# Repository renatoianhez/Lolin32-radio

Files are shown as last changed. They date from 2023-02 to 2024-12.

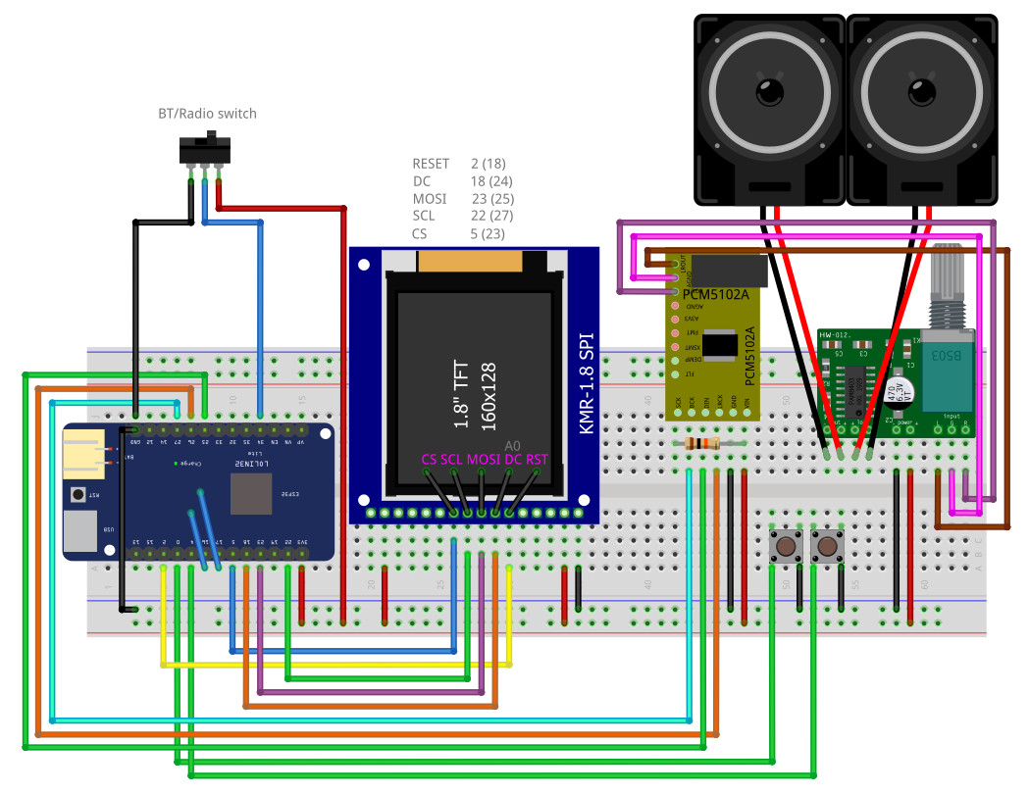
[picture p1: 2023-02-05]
RadioeBT/Fritzing.jpg

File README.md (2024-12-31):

# Lolin32-radio
This is another project like others out there: a web radio with ESP32.

New update: I put a bluetooth mode through an SPDT switch. Look in the RadioeBT folder.

The best update so far: it's possible to update your list of radio stations via a text file in GIST! See it on RadioWeb example. This is important because radio stations often change their URLs. In my case, as I make the radio sets as gifts to my friends, I won't need to get the sets back to update them. Although it is a good reason to visit them!

This radio uses Lolin32 Lite (with a PSRAM update, which makes it equivalent to an ESP32 WROVER), a 1.8'' SPI screen and I2S with PCM5102 + PAM8403 amp:



The libraries used are:

ESP32-audioI2S: https://github.com/schreibfaul1/ESP32-audioI2S

TFT_eSPI: https://github.com/Bodmer/TFT_eSPI

Bluetooth: https://github.com/pschatzmann/ESP32-A2DP

Add the PSRAM:



https://blog.pagefault-limited.co.uk/lolin32-lite-esp32-8mb-psram-upgrade-mod

With PSRAM, the Lolin32 Lite works like a WROVER Kit. The Arduino IDE configuration looks like this:


After audio library updates, it is possible to play HLS streams!
I'm assembling it in a wooden box.

Imagem do WhatsApp de 2023-02-05 à(s) 17 16 38



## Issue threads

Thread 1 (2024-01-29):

No Issue, just a question:  How to transmit a radio stream to a bluetooth speaker

chess-levin, 2024-01-29:
Hello @renatoianhez ,
thank you for sharing your excellent work here on github!

I've recently built my own web radio based on this projects

* https://github.com/schreibfaul1/ESP32-audioI2S/tree/master/examples/Better_WiFi_throughput
* https://github.com/schreibfaul1/ESP32-MiniWebRadio

I had troubles to get a smooth, uninterrupted audio experience unless I found the previously mentioned code/project. The TCP-stream broke down every now and then. So I had to reconfigure the TCP-Settings used by the Arduino framework.

Now the receiving part is fine, but I'm missing a way to transmit the sound to one of my Bluetooth speakers. As a workaround I bought a TX/RX-Transceiver (amazon) that converts the analogue lineout-signal and sends it via Bluetooth to a speaker. Obviously it is nuts, to first send the audio stream through a DAC + a class D amp and afterwards convert it back to a digital signal. So your project seems to be a solution to this problem.

During my research I found several sources that were saying, ESP32 is not good for transmitting audio via BT. I was wondering if receiving a audio-stream via TCP and sending audio via BT in parallel is a problem that causes interrupted sound and therefore a bad listening experience.

Maybe you could share some deeper information on your BT solution and about the sound quality.

As far as I understand you use BT as an input source and not as an output sink - correct?

Thank you very much in advance!

renatoianhez, 2024-01-29:
Yes! The Bluetooth function on my radio (when selected on a rear button) is only the reception of the signal generated by another device, such as a cell phone playing music via Spotify. In this case, the radio function is switched off.
Perhaps, in your case, a small dedicated Bluetooth transmission board like [this one](https://pt.aliexpress.com/item/1005005777451417.html) will be the solution to take the audio signal and transmit it.
I believe that transmitting data simultaneously with receiving stream data is also possible using different cores in the ESP32 that are dual core (it would not be possible in the ESP32 C3, for example). However, I don't really understand how to dedicate a task to a specific core. In the [Wolle's audio library](https://github.com/schreibfaul1/ESP32-audioI2S) there are some clues on how to do this.

chess-levin, 2024-01-30:
Tank you for answering my question.
I already ordered this KCX_BT_EMITTER, but as I wrote overall this results in an odd signal chain.
So I'm going to ask pschatzman the author of [audio-tools](https://github.com/pschatzmann/arduino-audio-tools/tree/main), if he could give me tome tips, to get me started on this topic.

chess-levin, 2024-01-30:
So **Wifi & BT is not working together** on an ESP32: https://github.com/pschatzmann/ESP32-A2DP/wiki/WIFI-and-A2DP-Coexistence

Closed 2024-01-30.

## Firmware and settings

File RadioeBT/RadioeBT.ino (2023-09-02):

#include <Arduino.h>
#include <TFT_eSPI.h> // Screen lib
#include <SPI.h> // SPI
#include <WiFi.h> // WiFi lib
#include <WiFiMulti.h> // Multi address WiFi
#include "Audio.h" // Audio lib
#include "examples/320 x 240/Free_Font_Demo/Free_Fonts.h" // Fonts
#include "BluetoothA2DPSink.h" // Bluetooth lib

#define canalPraCima  0   // Switch stations
#define canalPraBaixo 4
#define I2S_DOUT      25  // Audio I2S pins
#define I2S_BCLK      27
#define I2S_LRCK      26
#define modoAparelho  34  // Switch radio-bluetooth

bool mudouEstacao;
int radioTocando;
char* tituloBT;
char* artistaBT;
char* albumBT;

TFT_eSPI tela = TFT_eSPI(); // Screen pins are in library
Audio audio;
BluetoothA2DPSink a2dp_sink;
WiFiMulti outrosWiFi;
bool connected = true;

//Radios and URL's
const char* nomeRadio[30] = {
  "Antena 1",
  "Kiss",
  "Eldorado FM", 
  "Cultura",
  "Itatiaia", 
  "Dominicana",  
  "BFF.fm", 
  "Saudade", 
  "Radio USP", 
  "CBN BH",
  "Radio UFMG",
  "Tribuna",
  "Smooth Jazz",
  "Louge FM",
  "JB FM",
  "Chante France",
  "Guerrilla",
  "Oldie Antenne",
  "Alvorada",
  "Sarau",
  "RadioNOS",
  "Inconfidencia",
  "Axe Bahia",
  "Seresta aoLuar",
  "XFM",
  "Super 70s",
  "Classic Hits",
  "WROD",
  "Univers. UFES",
  "Tonic Ska"
};
const char* tipoRadio[30] = {
  "FM - Hits Internacional",
  "FM - Rock",
  "FM - Noticia/Musica",
  "FM - MPB",
  "AM - Noticia/Musica",
  "Web - Salsa",
  "Web - Indie/Wolrd",
  "FM - Flash Back",
  "FM - MPB",
  "FM - Noticias",
  "FM - MPB/Varios",
  "FM - Hits/Flash Back",
  "Web - Jazz",
  "Web - Acustico/Lounge",
  "FM - Hits/Flash Back",
  "Web - Chanson Francaise",
  "Web - Alternative/Rock",
  "Web - Flash Back/Rock",
  "FM - Hits/Flash Back",
  "FM - MPB/Seresta",
  "Web - Dub/Reggae",
  "FM - MPB/Noticias",
  "Web - Axe",
  "Web - Seresta",
  "FM - Rock",
  "Web - Flash Back/Rock",
  "Web - Flash Back/Rock",
  "FM - Rock",
  "FM - MPB/Samba",
  "Web - Ska/Reggae"
};

const char* cidadeRadio[30] = {
  "Sao Paulo SP",
  "Sao Paulo SP",
  "Sao Paulo SP",
  "Sao Paulo SP",
  "Belo Horizonte MG",
  "Santo Domingo - R. Dom",
  "San Francisco CA - USA",
  "Santos SP",
  "Sao Paulo SP",
  "Belo Horizonte MG",
  "Belo Horizonte MG",
  "Vitoria ES",
  "New York - USA",
  "Kiev - Ucrania",
  "Rio de Janeiro RJ",
  "Paris - Franca",
  "Sarasota FL - USA",
  "Bayern - Alemanha",
  "Belo Horizonte MG",
  "Conservatoria RJ",
  "Fortaleza CE",
  "Belo Horizonte MG",
  "Salvador BA",
  "Taubate SP",
  "Londres - UK",
  "Waynesboro VA - EUA",
  "Waynesboro VA - EUA",
  "Daytona Beach FL - EUA",
  "Vitoria ES",
  "Londres - UK"
};
String urlRadio[] = {    // GL = glitches, OK = no glitches
  "https://antenaone.crossradio.com.br/stream/1;", // Antena 1 OK no tags
  "http://cloud2.cdnseguro.com:23538/;", // Kiss FM OK
  "https://eldoradolive02.akamaized.net/hls/live/2043453/eldorado/master.m3u8", // Eldorado OK no tags
  "https://radiocultura2.jmvstream.com/stream", // Cultura OK no tags
  "http://8903.brasilstream.com.br:8903/stream?1616578451161", // Itatiaia OK
  "http://radio.domiplay.net:2002/;", // Dominicana OK
  "https://ais-sa2.cdnstream1.com/2053_128.mp3", // BFF.FM GL
  "https://24073.live.streamtheworld.com/SAUDADE_FMAAC.aac", // Saudade OK
  "http://flow.emm.usp.br:8007/radiousp-128.mp3", // USP OK no tags
  "https://26513.live.streamtheworld.com/CBN_BHAAC.aac", // CBN OK
  "http://150.164.63.210:8000/aovivo.mp3", // UFMG OK no tags
  "http://cast.midiaip.com.br:6060/stream?1506557548760", // Tribuna GL+
  "https://hestia2.cdnstream.com/1078_128?cb=696226.mp3",  // Smooth Jazz GL
  "http://cast.loungefm.com.ua/acoustic128?1410329161003.mp3", // Louge FM GL
  "https://24083.live.streamtheworld.com/JBFMAAC.aac", // JB GL+
  "https://chantefranceemotion.ice.infomaniak.ch/chantefranceemotion-96.aac", // Chante France GL
  "http://s2.stationplaylist.com:9460/guerrilla", // Guerrilla OK
  "https://s7-webradio.oldie-antenne.de/oldie-antenne", // Antenne Oldies GL+++
  "http://20323.live.streamtheworld.com/RADIO_ALVORADAAAC_SC", // Alvorada OK
  "https://s17.maxcast.com.br:8783/live", // Sarau OK
  "https://nos.radio.br/stream/8/;", // RadioNOS OK
  "https://8446.brasilstream.com.br/stream", // Inconfidencia FM OK
  "http://euroticast5.euroti.com.br:8070/;", // Axe BA OK
  "http://50.3.30.111:8042/stream", // Seresta ao Luar OK
  "http://media-ice.musicradio.com/RadioXLondon", // XFM GL+
  "http://relay.181.fm:8066/", // 181 Super 70 OK
  "http://relay.181.fm:8132/", // 181 Classic OK
  "http://ice7.securenetsystems.net/WROD", // WROD GL+
  "http://8642.brasilstream.com.br/stream?identifica=9725815160273912000&rand=9201410188400340000", //UFES OK
  "https://eu10.fastcast4u.com/tonicska" // Tonic Ska GL++
};

void sobeCanal() {
  // Se apertar o botao pra subir uma estacao:
  radioTocando = radioTocando + 1;          // increments index
  tela.fillScreen(TFT_BLACK);
  tela.setTextColor(TFT_RED, TFT_WHITE);
  tela.setCursor(0, 0, 4);
  tela.println("Sintonizando!");
  delay(1000); // delay for button
  if (radioTocando > 29) {     // Tests if is the last station of list
    radioTocando = 0;         // if yes, go to the first
  }
}

void desceCanal() {
  radioTocando = radioTocando - 1;        // decrements the index
  tela.fillScreen(TFT_BLACK);
  tela.setCursor(0, 0, 4);
  tela.setTextColor(TFT_RED, TFT_WHITE);
  tela.println("Sintonizando!");
  delay(1000); // uma pausa pra largar o botao
  if (radioTocando < 0) { 
    radioTocando = 29; 
  }
}

void mudouEstacaoMesmo() {
  tela.setFreeFont(FF5);
  tela.fillScreen(TFT_BLACK);
  tela.fillRect(0, 0, 160, 28, TFT_WHITE);
  int centro = 77 - (11 * ((strlen(nomeRadio[radioTocando])) / 2));
  tela.setCursor(centro, 18);
  tela.setTextColor(TFT_BLUE); //blue text
  tela.println(nomeRadio[radioTocando]); // centralizes radio name
  tela.setTextFont(2);
  tela.setCursor(0, 30);
  tela.setTextColor(TFT_ORANGE);
  tela.println(cidadeRadio[radioTocando]);
  tela.setCursor(0, 45, 2);
  tela.setTextColor(TFT_YELLOW);
  tela.println(tipoRadio[radioTocando]);
  audio.connecttohost(urlRadio[radioTocando].c_str());
  delay(500);
}
void audio_info(const char *info) {
  Serial.print("info        ");
  Serial.println(info);
}

void audio_showstreamtitle(const char *titulo) { // To show tags
  tela.setCursor(0, 60, 2);
  tela.setTextColor(TFT_CYAN, TFT_BLACK);
  tela.println("Tocando agora:");
  tela.setCursor(0, 75, 2);
  tela.println("                                                                                    "); //Clean tags
  tela.setCursor(0, 75, 2);
  tela.println(titulo);
}

void avrc_metadata_callback(uint8_t id, const uint8_t *text) {
  Serial.printf("==> AVRC metadata rsp: attribute id 0x%x, %s\n", id, text);
  tela.setFreeFont(FF5);
  tela.fillScreen(TFT_BLACK);
  tela.fillRect(0, 0, 160, 28, TFT_WHITE);
  tela.setCursor(28, 18);
  tela.setTextColor(TFT_BLUE); 
  tela.println("BLUETOOTH");
  tela.setTextFont(2);
  tela.setCursor(0, 30);
  switch (id) {
    case ESP_AVRC_MD_ATTR_TITLE:
      tituloBT = (char*) text;
      break;
    case ESP_AVRC_MD_ATTR_ARTIST:
      artistaBT = (char*) text;
      break;
    case ESP_AVRC_MD_ATTR_ALBUM:
      albumBT = (char*) text;
      break;
  }
  tela.setTextColor(TFT_ORANGE);
  tela.println(a2dp_sink.get_peer_name());  // Shows the name of source
  tela.setTextColor(TFT_PINK);
  tela.println(tituloBT);
  tela.setTextColor(TFT_YELLOW);
  tela.println(artistaBT);
  tela.setTextColor(TFT_LIGHTGREY);
  tela.println(albumBT);
}

void setup() {
  pinMode(canalPraCima, INPUT_PULLUP); // Button mode
  pinMode(canalPraBaixo, INPUT_PULLUP);
  pinMode(modoAparelho, INPUT);
  Serial.begin( 115200 );
  tela.init(); // Display init
  tela.setRotation(1); // Screen mode portrait
  tela.invertDisplay(1); // Color adjust for the TFT
  outrosWiFi.addAP("xxx", "xxx"); // WiFi data (user, passw)
  //outrosWiFi.addAP("xxx", "xxx"); // Others WiFi
  //outrosWiFi.addAP("xxx","xxx");

  if (digitalRead(modoAparelho)) {  //If radio mode
    radioTocando = random(0, 30); // Sort the first station
    mudouEstacao = true;
    WiFi.disconnect(); // Wifi connection
    WiFi.mode(WIFI_STA);
    while (outrosWiFi.run() != WL_CONNECTED) delay(1500);

    audio.setPinout(I2S_BCLK, I2S_LRCK, I2S_DOUT); // Radio config
    audio.setVolume(16); // volume zero to 21
    // audio.setConnectionTimeout(2000, 7200); // Grant connection
    audio.setTone(4, 0, 4); // Equalizator bass - mid - terble (-40 to 6)
    audio.setBufsize(0, 4000000);
    // audio.forceMono(true); // Mono
    // audio.setBalance(0); // Balance (-16 to 16)
  }
  else {
    i2s_pin_config_t my_pin_config = {  //If Bluetooth mode
      .bck_io_num = 27,
      .ws_io_num = 26,
      .data_out_num = 25,
      .data_in_num = I2S_PIN_NO_CHANGE
    };
    a2dp_sink.set_pin_config(my_pin_config);
    a2dp_sink.set_avrc_metadata_callback(avrc_metadata_callback);
    a2dp_sink.set_auto_reconnect(true);
    a2dp_sink.start("BTRadio1");
  }
}

void loop() {
  if (digitalRead(modoAparelho)) { // If the mode switch is radio
    audio.loop();
    if (digitalRead(canalPraCima) == LOW) {//If up station
      sobeCanal();
      mudouEstacao = true;
    }
    if (digitalRead(canalPraBaixo) == LOW) {//If down station
      desceCanal();
      mudouEstacao = true;
    }
    if (mudouEstacao) {  
      mudouEstacaoMesmo();
      mudouEstacao = false;
    }
  }
}

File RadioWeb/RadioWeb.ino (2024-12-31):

#include <ESP_I2S.h> // I2S library for bluetooth
#include <wav_header.h> //Required for the above library
#include <Arduino.h>
#include <TFT_eSPI.h> // Screen library
#include <SPI.h> // SPI
#include <WiFiMulti.h> // For more than one WiFi location
#include "Audio.h" // Audio lib
#include "examples/320 x 240/Free_Font_Demo/Free_Fonts.h" // Fonts
#include "BluetoothA2DPSink.h" // For Bluetooth
#include <HTTPClient.h> // To access the radio station information link

#define canalPraCima  0   // 0 for Lolin32 - 15 for Wrover - Buttons to change the radio station
#define canalPraBaixo 4
#define I2S_DOUT      25  // Audio I2S pins
#define I2S_BCLK      27
#define I2S_LRCK      26
#define modoAparelho  34  // Radio-Bluetooth selector switch

bool mudouEstacao;
int radioTocando;
char* tituloBT;
char* artistaBT;
char* albumBT;

TFT_eSPI tela = TFT_eSPI(); // ATTENTION The screen pins are defined in the library
Audio audio;
I2SClass i2s;
BluetoothA2DPSink a2dp_sink(i2s);
WiFiMulti outrosWiFi;
HTTPClient http;
bool connected = true;

//Radios e enderecos
String conteudoBaixado;
String tudo[120];
String nomeRadio[30];
String tipoRadio[30];
String cidadeRadio[30];
String urlRadio[30];
String endTudo = "https://gist.githubusercontent.com/renatoianhez/555bf033ddc5831d16e2602b5c48a909/raw";
int indice = 0;

void baixaDados(const String& urlDado, int maxTokens, String* tokens) {
  http.begin(urlDado);
  int httpCode = http.GET();
  if (httpCode == HTTP_CODE_OK) {
    conteudoBaixado = http.getString();
    Serial.println("Radio data file downloaded successfully");
  }
  else {
    Serial.printf("Failed to download file. HTTP error code: %d\n", httpCode);
  }
  http.end();
  int startIndex = 0;
  int endIndex = 0;
  int tokenIndex = 0;
  while (endIndex >= 0 && tokenIndex < maxTokens) {
    endIndex = conteudoBaixado.indexOf('\n', startIndex);
    if (endIndex >= 0) {
      tokens[tokenIndex] = conteudoBaixado.substring(startIndex, endIndex);
      startIndex = endIndex + 1;
    } else {
      tokens[tokenIndex] = conteudoBaixado.substring(startIndex);
    }
    tokenIndex++;
  }
}

void sobeCanal() {
  // If you press the button to go up one station:
  radioTocando = radioTocando + 1;          // increase the index
  tela.fillScreen(TFT_BLACK);
  tela.setTextColor(TFT_RED, TFT_WHITE);
  tela.setCursor(0, 0, 4);
  tela.println("Sintonizando!");
  delay(1000); // a break to release the button
  if (radioTocando > 29) {     // Test if you have passed the last station on the list
    radioTocando = 0;         // if yes, go to the first station of the playlist
  }
}

void desceCanal() {
  radioTocando = radioTocando - 1;        // decrements the index
  tela.fillScreen(TFT_BLACK);
  tela.setCursor(0, 0, 4);
  tela.setTextColor(TFT_RED, TFT_WHITE);
  tela.println("Sintonizando!");
  delay(1000); // uma pausa pra largar o botao
  if (radioTocando < 0) {     // Test if it passed below the first on the list
    radioTocando = 29;      // If yes, go to the last one on the playlist.
  }
}

void mudouEstacaoMesmo() {
  tela.setFreeFont(FF5);
  tela.fillScreen(TFT_BLACK);
  tela.fillRect(0, 0, 160, 28, TFT_WHITE);
  int centro = 77 - (11 * ((nomeRadio[radioTocando].length())) / 2);
  tela.setCursor(centro, 18);
  tela.setTextColor(TFT_BLUE); //blue text
  tela.println(nomeRadio[radioTocando]); // centralized radio name
  tela.setTextFont(2);
  tela.setCursor(0, 30);
  tela.setTextColor(TFT_ORANGE);
  tela.println(cidadeRadio[radioTocando]);
  tela.setCursor(0, 45, 2);
  tela.setTextColor(TFT_YELLOW);
  tela.println(tipoRadio[radioTocando]);
  audio.connecttohost(urlRadio[radioTocando].c_str());
  delay(500);
}
void audio_info(const char *info) {
  Serial.print("info        ");
  Serial.println(info);
}

void audio_showstreamtitle(const char *titulo) { // To show the name of the song and singer (some stations do not provide this)
  tela.setCursor(0, 60, 2);
  tela.setTextColor(TFT_CYAN, TFT_BLACK);
  tela.println("Playing now:");
  tela.setCursor(0, 75, 2);
  tela.println("                                                                                    "); //To clean names
  tela.setCursor(0, 75, 2);
  tela.println(titulo);
}

void avrc_metadata_callback(uint8_t id, const uint8_t *text) {  // Routine to show music data in bluetooth mode
  Serial.printf("==> AVRC metadata rsp: attribute id 0x%x, %s\n", id, text);
  tela.setFreeFont(FF5);
  tela.fillScreen(TFT_BLACK);
  tela.fillRect(0, 0, 160, 28, TFT_WHITE);
  tela.setCursor(28, 18);
  tela.setTextColor(TFT_BLUE);
  tela.println("BLUETOOTH");
  tela.setTextFont(2);
  tela.setCursor(0, 30);
  switch (id) {
    case ESP_AVRC_MD_ATTR_TITLE:
      tituloBT = (char*) text;
      break;
    case ESP_AVRC_MD_ATTR_ARTIST:
      artistaBT = (char*) text;
      break;
    case ESP_AVRC_MD_ATTR_ALBUM:
      albumBT = (char*) text;
      break;
  }
  tela.setTextColor(TFT_ORANGE);
  tela.println("Conectado a: ");
  tela.println(a2dp_sink.get_peer_name());
  tela.setTextColor(TFT_PINK);
  tela.println(tituloBT);
  tela.setTextColor(TFT_YELLOW);
  tela.println(artistaBT);
  tela.setTextColor(TFT_LIGHTGREY);
  tela.println(albumBT);
}
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

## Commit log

2022-07-28 Update Fritzing files
    [Radio Lolin32+MAX98356.fzz, Radio Lolin32+PCM5102+PAM8403.fzz]
2024-04-23 Version to update to ESP32 3.0 - Bluetooth issue
2024-04-23 Try to update to ESP32 3.0 - Bluetooth issue
2024-12-30 Update to 3.0.7 ESP32 Arduino version
